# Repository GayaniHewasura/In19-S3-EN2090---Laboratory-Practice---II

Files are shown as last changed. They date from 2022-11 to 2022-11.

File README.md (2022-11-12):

# In19-S3-EN2090---Laboratory-Practice---II
In our third-semester lab project, an analog function generator implemented using the basic elements such as OPAMPs, transistor, and analog components was completed successfully. 
Project Report
FUNCTION GENERATOR
1. G.I. Hewasura 190234E - Square Wave, Triangular Wave, PWM generation
2. T. Jayabawan 190250A - Swatooth wave generation
3. D.R. Jayasinghe 190262L - Power supply
4. L.H.T.V. Jayawardane 190274B - Sine wave generation
Supervisor: Mr. Pasan Dissanayake
November 12, 2022

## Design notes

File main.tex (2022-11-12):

\documentclass[11pt]{article}
\usepackage[utf8]{inputenc}
\usepackage[a4paper, margin=1in]{geometry}
\usepackage{graphicx}
\usepackage{amssymb}
\usepackage{gensymb} % for advanced symbols
\usepackage{amsmath}
\usepackage{amssymb}
\usepackage{multicol}
\setlength{\columnsep}{1cm}
\usepackage{wrapfig}
\usepackage{float}
\usepackage{appendix}
\usepackage{hyperref}
\usepackage{float}

\graphicspath{ {Images/} }
\hypersetup{
    colorlinks=true,
    linkcolor=blue,
    filecolor=magenta,      
    urlcolor=blue,
    pdftitle={Overleaf Example},
    pdfpagemode=FullScreen,
    }
\urlstyle{same}

\begin{document}

\begin{center}
\textbf{Department of Electronic and Telecommunication Engineering\\[10 pt]University of Moratuwa \\[20 pt] EN2090  Laboratory Practice - II \\[20 pt]}



\begin{huge}
\vspace{30mm}
\textbf{Project Report \\[20 pt] FUNCTION GENERATOR} \\[100 pt]
\end{huge}

\begin{tabular}{c c c }
1. & G.I. Hewasura & 190234E  \\
2. & T. Jayabawan  & 190250A  \\ 
3. & D.R. Jayasinghe & 190262L  \\  
4. & L.H.T.V. Jayawardane & 190274B
\end{tabular}

\textbf{\\[20 pt]Supervisor: Mr. Pasan Dissanayake\\[10 pt]}

\begin{large}
\today
\end{large}

\end{center}
\thispagestyle{empty} 
\newpage

\begin{multicols}{2}
[
\rule{\textwidth}{0.5pt}
\begin{abstract}
    Most of the electronics applications require various wave forms. From finding the characteristics of OPAMPs and diodes to testing the inner workings of the audio amplifier these wave forms are used. This report discusses about an analog function generator which can produce sine, square, triangular and saw tooth wave forms at the range of 20Hz to 20000Hz in frequency where the output voltage varies from -5v to 10v.
\end{abstract}
\rule{\textwidth}{0.5pt}
]
\tableofcontents

\section{Introduction}
Analog function generator is an electronic device which is implemented using the basic elements such as OPAMPs and other passive elements. This project "analog function generator" is made as a report covering the aspects of building it physically. First, the methodology used to implement the requirements is discussed. In this part the implementations with circuit diagrams and the principles are discussed. Next the results are described, for each wave forms the output through the oscilloscope are presented and the 

\section{Method}

\subsection{Waveform Generation}

\subsubsection{Square Wave with PWM}
An astable mutivibrator circuit is used in the generation process of the square wave where a Schmitt trigger logic gate is combined with a capacitor. The Schmitt trigger action changes the state between an upper and a lower threshold level as the input voltage signal increase and decrease about the input terminal. When the charge across the capacitor is higher than the Schmitt trigger higher threshold level since the voltage of the positive terminal is higher than the negative terminal, the output result to be logic “0” and vice versa. The period of the square wave changes with the R*C value, a potentiometer is used in the place of R to change the frequency. \\ The PWM signal is generated by sending the triangular waveform generated between the capacitor and the potentiometer through a comparator circuit. The duty cycle of the PWM signal is changed by varying the reference voltage in the positive terminal using the potentiometer in the comparator circuit. The PWM signal generated by the comparator  is sent through a rectifier circuit to achieve a half rectified the PWM signal.
\begin{figure}[H]
    \centering
    
    \caption{Astable Multivibrator Circuit}
    \label{fig:mesh1}
\end{figure}
\begin{figure}[H]
    \centering
    
    \caption{PWM signal genaration}
    \label{fig:mesh1}
\end{figure}
\subsubsection{Triangle Wave}
Triangular wave is extracted in between the capacitor and the potentiometer where the triangular wave is generated as a result of the charging and discharging of the capacitor.
\begin{figure}[H]
    \centering
    
    \caption{Square and triangular pulse generation}
    \label{fig:mesh1}
\end{figure}

\subsubsection{Sine Wave}
Tilan
\subsubsection{Sawtooth Wave}

In order to produce the sawtooth waveform, the magnitude should instantly come to zero from the peak value. To implement this a capacitor can be short circuited but using this the capacitor won’t charge initially. By using a transistor we can find an optimal solution. \\
Here the transistor is in cut-off region to be charged. When capacitor is charged up to required saturation level, a momentary positive pulse is applied at the base of the transistor to send it into saturation. In saturation $V_{CE} = 0$, so capacitor is short circuited and discharges quickly to zero. The positive pulses are given as a PWM signal with a very small duty cycle.

\begin{figure}[H]
    \centering
    
    \caption{Square and triangular pulse generation}
    \label{fig:mesh1}
\end{figure}

\subsection{Output Stage}
According to the given specifications the function generator must be able to drive 50\(\Omega\) load. In general an OPAMP can provide only upto 100mA current which is not enough to drive a 50\(\Omega\) load at 10V pk-pk. In order to accomplish this task we used an OPAMP buffer circuit containing transistor push-pull stage. The maximum current required is about 200mA (10V/50\(\Omega\)). For this we are using 2N2222A NPN and 2N2907A transistors which can support upto 800mA \(I_{C}\) current.

\begin{figure}[H]
    \centering
    
    \caption{Buffer Circuit (using OPAMPS and push-pull stage}
    \label{fig:mesh1}
\end{figure}

\section{Results}
After testing the following results could be obtained relating to different modules in the function generator circuits.

\subsection{Component Selection}

Following are the main components used in the implementation of the analogue function generator.
\vspace{-2mm}

\begin{itemize}
    \setlength\itemsep{-2mm}
    \item TL084CN Quad-OPAMP
    \item AD826AN Dual-OPAMP
    \item 2N2222A, 2N2907A, 2N3904 transistors
    \item resistors, potentiometers, capacitors, etc.
\end{itemize}

\subsubsection*{TL084CN}
TL084CN is a 14-pin Quad Operational Amplifier by Texas Instruments. It has a slew rate of \(20 \; V/\mu s\) and a unity gain bandwidth of 5.25MHz. All the signal generation tasks were carried out using 2 of these OPAMPs. This OPAMPs able to produce both low (40Hz) and high (20kHz) frequency signals with sufficient accuracy.  

\subsubsection*{AD826AN}
AD826AN is an 8-pin Dual Operational Amplifier by Analog Devices. Is has a very high slew rate of \(350 V\mu s\) and a unity gain bandwidth of 40-50MHz. This OPAMP was used in the output stage as a non-inverting amplifier and a buffer before the transistor push-pull stage.

\subsection{Square and PWM wave}
We used two capacitors (\(10nF\) and \(0.33\mu F\)) to achieve lower and higher frequencies respectively in the relaxation oscillator. The PWM control is done using the OPAMP comparator. The following images show rectified square waveforms with different PWM values.

\begin{figure}[H]
    \centering
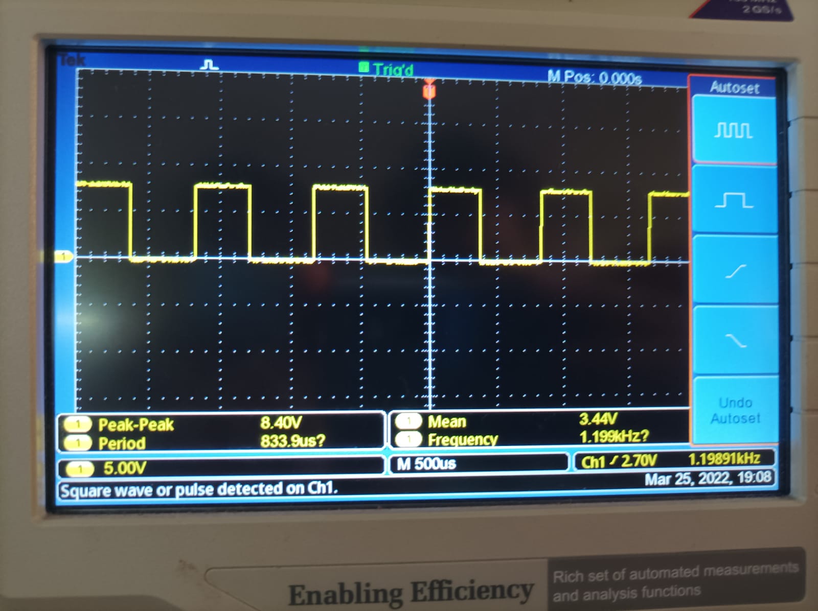
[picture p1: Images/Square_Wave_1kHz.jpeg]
    
    \caption{1kHz Square Wave Signal}
    \label{fig:mesh2}
\end{figure}

\begin{figure}[H]
    \centering
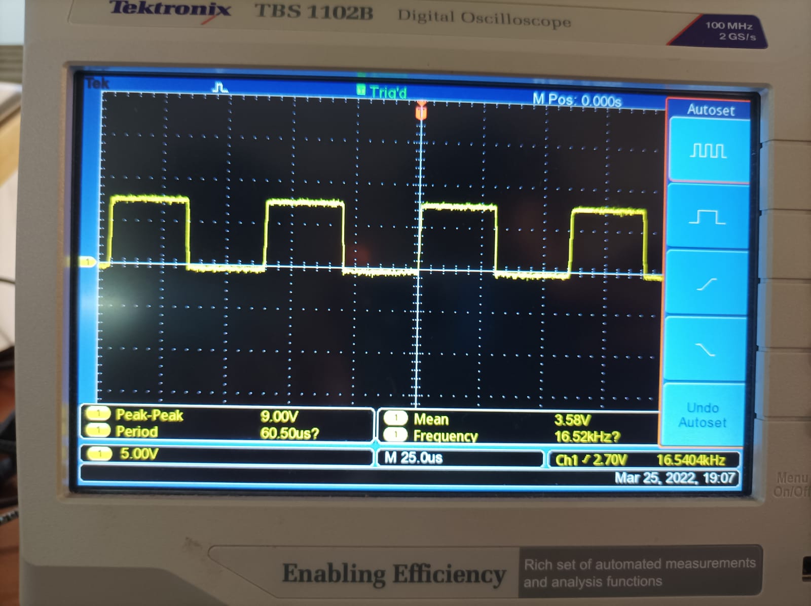
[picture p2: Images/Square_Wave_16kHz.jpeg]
    
    \caption{16kHz Square Wave Signal}
    \label{fig:mesh2}
\end{figure}

\begin{figure}[H]
    \centering
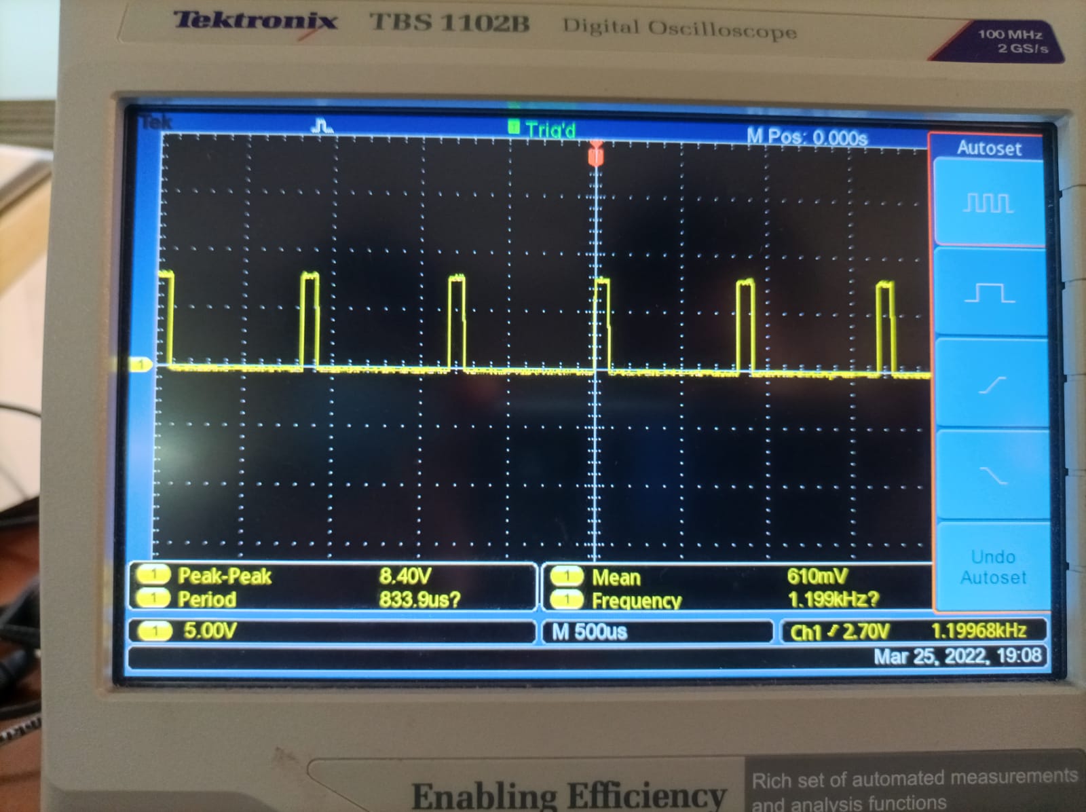
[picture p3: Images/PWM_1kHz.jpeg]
    
    \caption{PWM control of square wave}
    \label{fig:mesh3}
\end{figure}

\begin{figure}[H]
    \centering
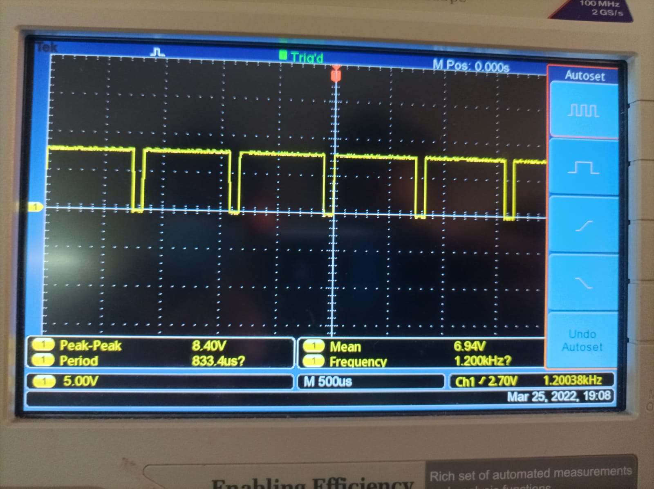
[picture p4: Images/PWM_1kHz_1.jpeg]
    
    \caption{PWM control of square wave}
    \label{fig:mesh4}
\end{figure}

\subsection*{Triangle Wave}

The triangle waveform is obtained as the voltage across the capacitor from the relaxation oscillator. 

\begin{figure}[H]
    \centering
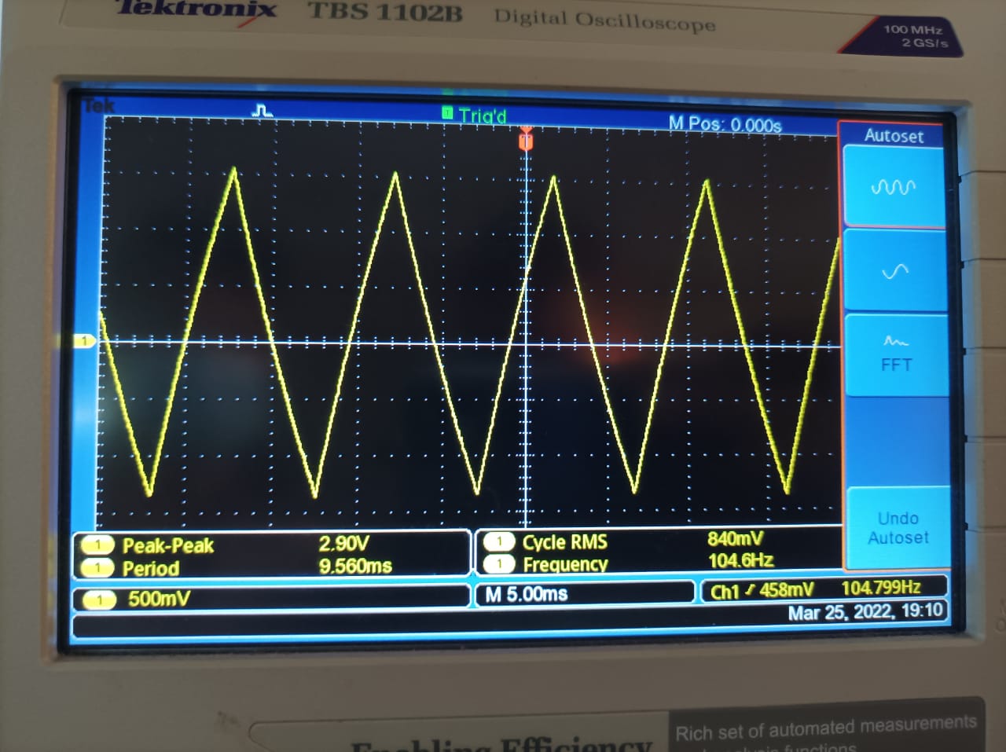
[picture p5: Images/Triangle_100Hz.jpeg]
    
    \caption{100Hz triangle waveform}
    \label{fig:mesh5}
\end{figure}

\begin{figure}[H]
    \centering
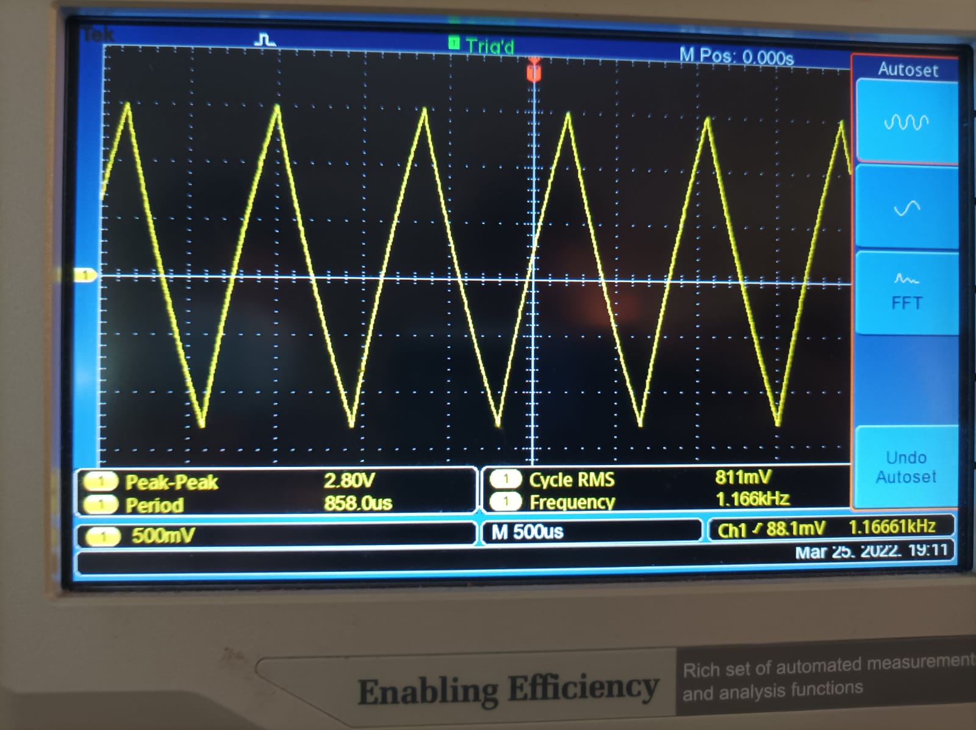
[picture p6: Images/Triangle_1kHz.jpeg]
    
    \caption{1kHz triangle waveform}
    \label{fig:mesh6}
\end{figure}

\begin{figure}[H]
    \centering
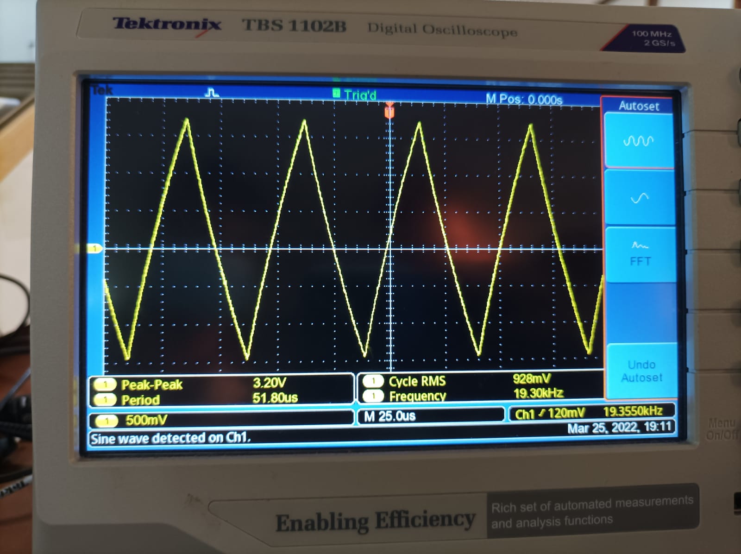
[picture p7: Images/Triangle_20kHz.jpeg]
    
    \caption{20kHz triangle waveform}
    \label{fig:mesh7}
\end{figure}

\subsection*{Sine Wave}

The sine wave is obtained after the triangle waveform is filtered from the low pass filters. From the four filters we used the accurate wave forms could be obtained.

\begin{figure}[H]
    \centering
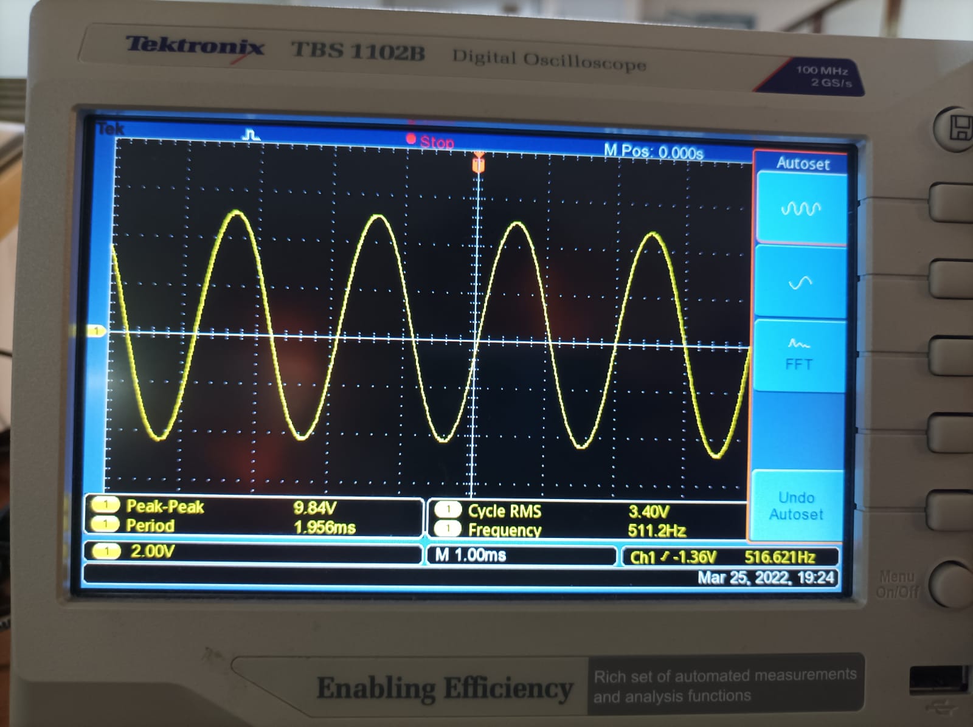
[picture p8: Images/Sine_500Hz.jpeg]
    
    \caption{500Hz sine waveform}
    \label{fig:mesh5}
\end{figure}

\begin{figure}[H]
    \centering
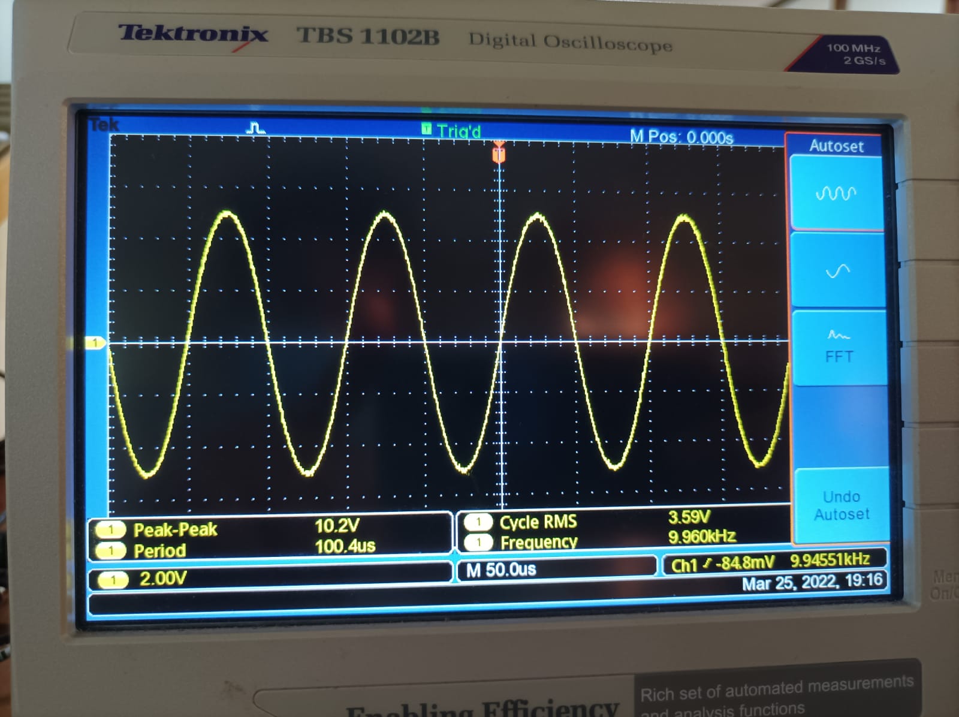
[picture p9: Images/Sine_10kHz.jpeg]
    
    \caption{10kHz sine waveform}
    \label{fig:mesh6}
\end{figure}

\begin{figure}[H]
    \centering
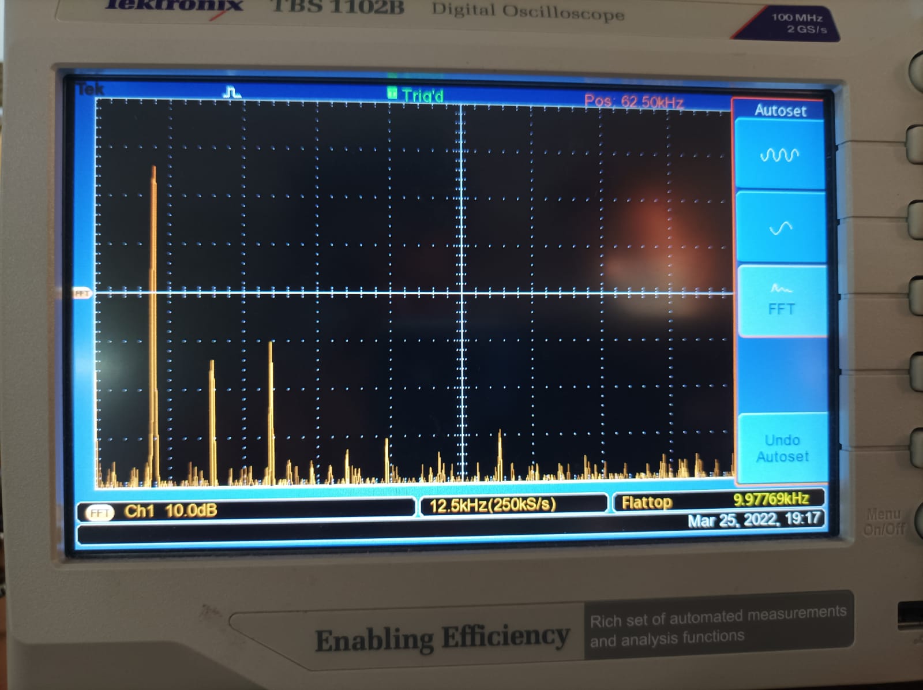
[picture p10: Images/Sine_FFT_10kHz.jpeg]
    
    \caption{Frequency spectrum of 10kHz sine waveform}
    \label{fig:mesh7}
\end{figure}

\section{Discussion}

Following are some of the issues we encountered when designing the analogue function generator. We were able to fix some these issues.

\subsubsection*{Shape of the Triangle Waveform}
The triangle wave which was obtained as the capacitor voltage of the relaxation oscillator, was not exactly triangular in shape. At closer inspection it is possible to see a curve similar to that of a capacitor charging and discharging. This could have been avoided by integrating the square wave, using an \textbf{OPAMP integrator} circuit instead. But we decided not to implement it because, the waveform was very nearly triangular. 
\\
\textbf{\textcolor{red}{image of a distorted triangle wave}}

\subsubsection*{Amplitude reduction of Sine and Sawtooth functions when increasing frequency}

This is another issue that could not be completely resolved in our design. As the frequency is increased, the amplitude of both sine and sawtooth wave reduced dramatically. This happened in each waveform due to the following reason;
\begin{itemize}
    \item \textbf{Sine wave} - Once the frequency was increased past the cutoff frequency of the filter, the gain reduction caused the amplitude of the waveform to drop. 
    \item \textbf{Sawtooth Wave} - \textbf{\textcolor{red}{Reason for the decrease in amplitude}}
\end{itemize}

The method currently used to overcome this issue is to, increase the amplitude at the output stage to counter balance the amplitude reduction resulted by frequency change.

\end{multicols}

\newpage

\section{Appendices}

\subsection{Appendix I - PCB Layout}

\begin{multicols}{2}
\begin{figure}[H]
    \centering
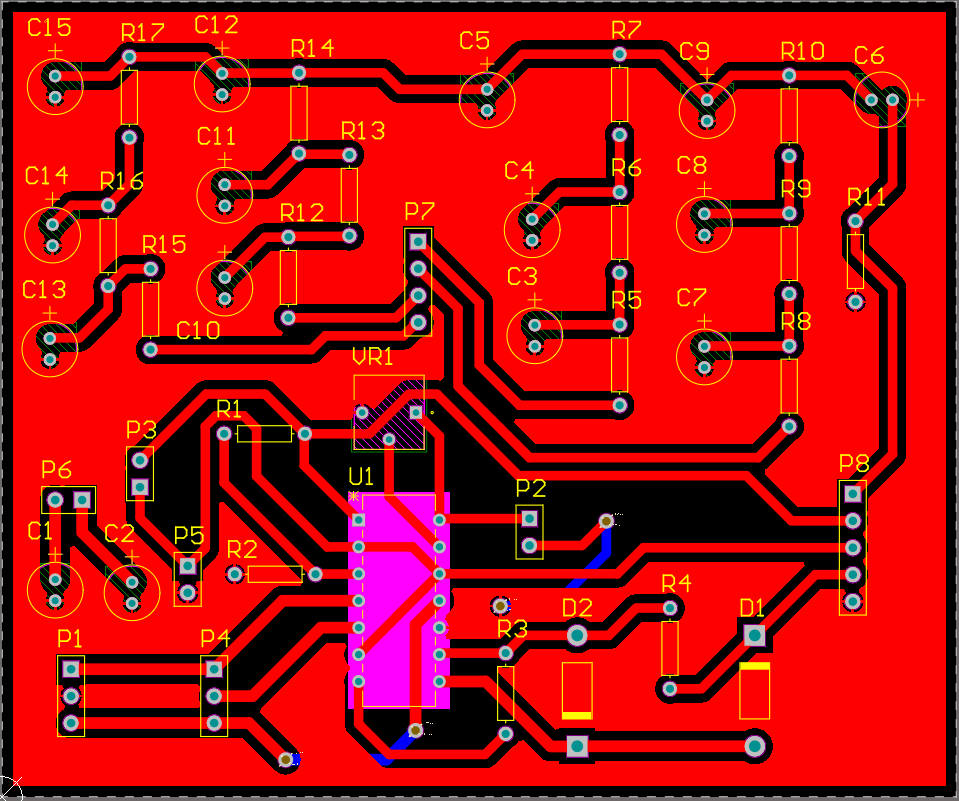
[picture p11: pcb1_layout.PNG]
    
    \caption{PCB 1 - Triangle, Square, Sine Wave generation}
    \label{fig:mesh6}
\end{figure}

\begin{figure}[H]
    \centering
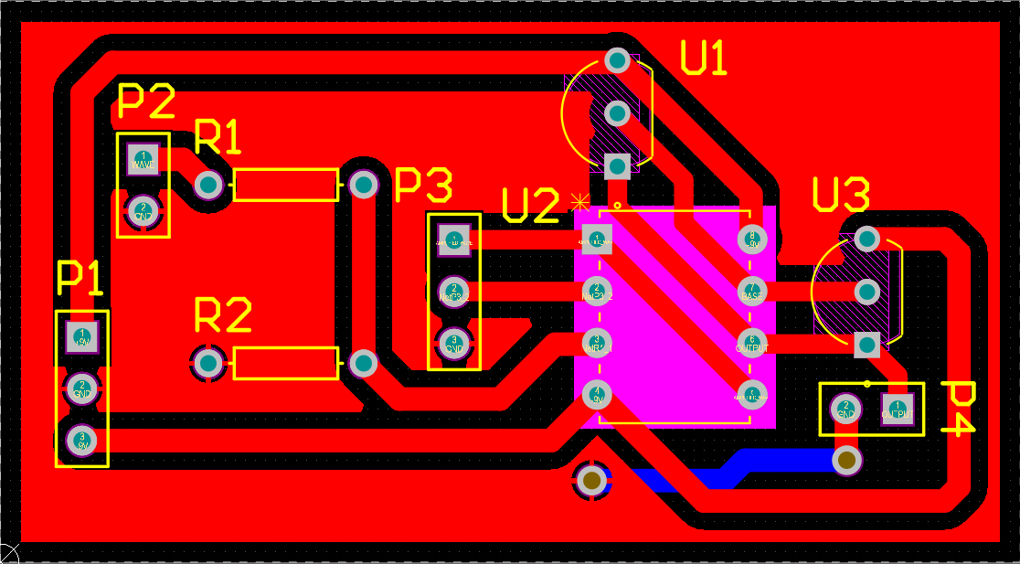
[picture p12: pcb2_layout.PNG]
    
    \caption{PCB 2 - Output Stage }
    \label{fig:mesh6}
\end{figure}

\begin{figure}[H]
    \centering
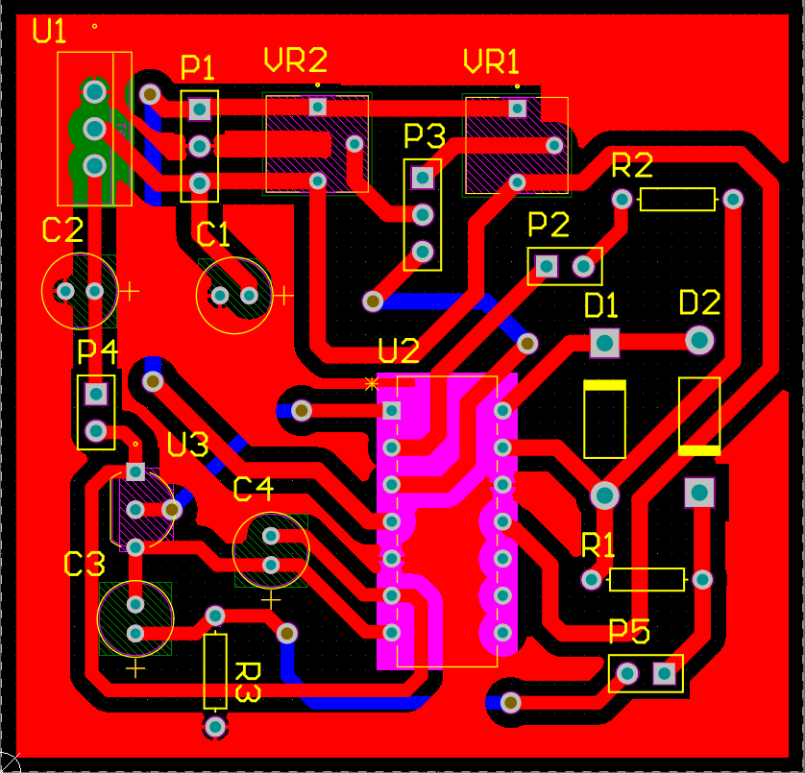
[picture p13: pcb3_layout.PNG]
    
    \caption{PCB 3 - Sawtooth Wave Generation}
    \label{fig:mesh6}
\end{figure}

\end{multicols}

\section{Appendix II - Enclosure}

\newpage

\section{Appendix III - Datasheet}

\rule{\textwidth}{0.5pt}

\begin{center}
    \begin{large}
    \textbf{Analogue Function Generator - Datasheet}
    \end{large}

\end{center}

\subsection*{Features}
\begin{itemize}
    \setlength\itemsep{-2mm}
    \item 5 output functions
    \item Adjustable frequency from 40Hz to 20kHz
    \item Amplitude can be adjusted within \(\pm\)7V
    \item Can drive small loads
\end{itemize}

\subsection*{Description}

Analogue Function Generator is designed completely using analogue electronic components and it is capable of producing the following output functions.
\begin{itemize}
    \setlength\itemsep{-2mm}
    \item Triangle Wave
    \item Square Wave (50\% duty)
    \item Square Wave PWM (variable duty cycle)
    \item Sine Wave
    \item Sawtooth Wave
\end{itemize}

The device can output these waveforms with minimum distortion approximately within a range of 40Hz - 20kHz. It is possible to adjust the amplitude of each of the waveforms within a range about of \(\pm\)7V. The fuction generator can be used for multiple electronics and communications applications such as testing equipments, analyse Audio Systems, etc.

\subsection*{Specifications}

\subsubsection*{Power Supply}

\begin{multicols}{2}
\begin{tabular}{ | c |  c |  c | }
\hline
\multicolumn{3}{| c  |}{Input} \\
\hline
Min. Input Voltage & 7 & V AC rms\\
\hline
Max. Input Voltage & 24 & V AC rms \\
\hline
Typ. Input Voltage & 9 - 15 & V AC rms \\
\hline

\end{tabular}

\begin{tabular}{ | c |  c |  c | }
\hline
\multicolumn{3}{| c  |}{Output} \\
\hline
Output Voltage & \(\pm\)9 & V DC\\
\hline
Max. Output Current & 1.5 & A \\
\hline
\end{tabular}
\end{multicols}

\subsubsection*{Function Generator Output}

\subsubsection*{Output Frequency Ranges}

\begin{tabular}{| c | c | c |}
\hline
Function &  Min. Frequency & Max. Frequency \\
\hline
Triangle & 41 Hz & ~30 kHz\\
\hline
Square (50\% Duty) & 44 Hz & ~20 kHz\\
\hline
Square Wave (PWM) & 44 Hz & ~22 kHz \\ 
\hline
Sine Wave & 80 Hz & ~20 kHz\\
\hline
Sawtooth Wave & 110 Hz & ~10 kHz \\ 
\hline
\end{tabular}

\vspace{5mm}
\begin{multicols}{2}
\subsubsection*{PWM Duty Cycle Range}

\begin{tabular}{| c | c | c |}
\hline
Frequency Range & Duty Cycle \\
\hline
40 - 1 kHz & 1.6\% - 98.5\% \\
\hline
1 - 10 kHz & 2\% - 97\% \\
\hline
10 - 20 kHz & 4\% - 95\% \\
\hline
\end{tabular}

\subsubsection*{Sine Filter Selection}

\begin{tabular}{| c | c | c |}
\hline
 & Frequency Range\\
\hline
Filter 1 & 44 Hz - 400 Hz \\
\hline
Filter 2 & 400 Hz - 2 kHz \\
\hline
Filter 3 & 2 kHz - 10 kHz \\
\hline
Filter 4 & 10 kHz - 20 kHz \\
\hline
\end{tabular}
\end{multicols}

\end{document}

\end{document}

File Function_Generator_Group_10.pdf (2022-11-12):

Department of Electronic and Telecommunication Engineering

University of Moratuwa

EN2090 Laboratory Practice - II


# Project Report

# FUNCTION GENERATOR

1. | G.I. Hewasura | 190234E
2. | T. Jayabawan | 190250A
3. | D.R. Jayasinghe | 190262L
4. | L.H.T.V. Jayawardane | 190274B

Supervisor: Mr. Pasan Dissanayake

November 12, 2022

Abstract
Most of the electronics applications require various wave forms. From finding the characteristics of OPAMPs and diodes to testing the inner workings of the audio amplifier these wave forms are used. This report discusses about an analog function generator which can produce sine, square, triangular and saw tooth wave forms at the range of 20Hz to 20000Hz in frequency where the output voltage varies from -5v to 10v.

## Contents

1 Introduction | 2
2 Methodology | 2
2.1 Waveform Generation . . . . | 2
2.1.1 | Square Wave and PWM | 2
2.1.2 | Triangle Wave . . . . | 3
2.1.4 | Sawtooth Wave . . . . | 3
2.4 Circuit Block Diagram . . . . | 5
3 Results | 5
3.1 Square and PWM wave . . . | 5
4 Discussion | 7
5 Member Contribution | 8
6 References | 8
7 Appendices | 9
7.1 Appendix I - PCB Layout . . | 9
8 Appendix II - Enclosure | 9
9 Appendix III - Datasheet | 10

## 1 Introduction

Analog function generator is an electronic device implemented using the basic elements such as OPAMPs, transistor and analogue components.Function generators are used for many application such as testing and design of electronic devices, etc. This reports presents the design and physical implementation of an analogue function generator. First, the methodology used to implement the requirements is presented. In this part the implementations with circuit diagrams and the principles are discussed. Next the results are described. For each wave forms the output through the oscilloscope are presented and in the final section the results and the possible further improvements are discussed.

## 2 Methodology

### 2.1 Waveform Generation

### 2.1.1 Square Wave and PWM

An astable mutivibrator circuit is used in the generation process of the square wave where a Schmitt trigger is combined with a capacitor. The Schmitt trigger action changes the state between an upper and a lower threshold level as the input voltage signal increase and decrease about the input terminal. When the charge across the capacitor is higher than the Schmitt trigger higher threshold level since the voltage of the positive terminal is higher than the negative terminal, the output result to be logic “0” and vice versa. The period of the square wave changes with the RC value, a potentiometer is used as R to change the frequency.
The PWM signal is generated by sending the triangular waveform, generated at the capacitor, through a comparator circuit. The duty cycle of the PWM signal is changed by varying the reference voltage of the comparator. A precision rectifier circuit is used to rectify the square and PWM waveforms. Following equation is used to determine the period(T) of the square/triangle wave output of the astable multivibrator circuit.

β =

R1
R1 + R2

T = 2RC ln(

1 + β
1 − β

)

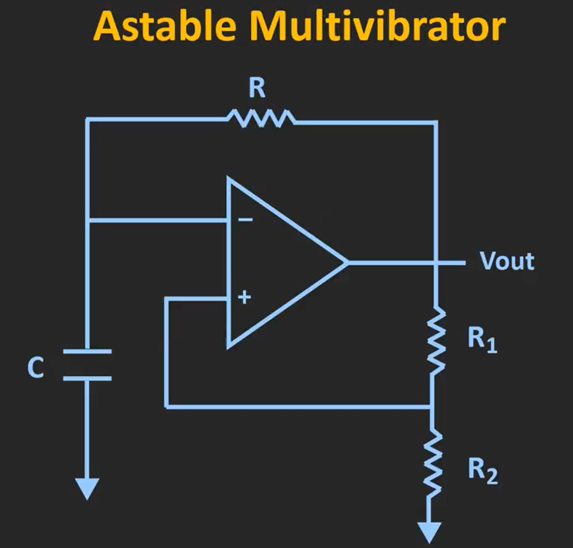
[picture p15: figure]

Figure 1: Astable Multivibrator Circuit

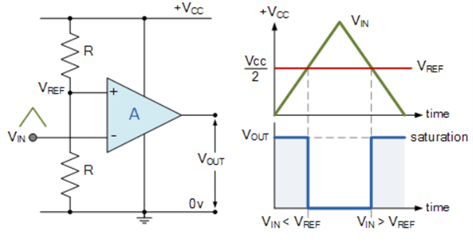
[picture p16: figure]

Figure 2: PWM signal genaration

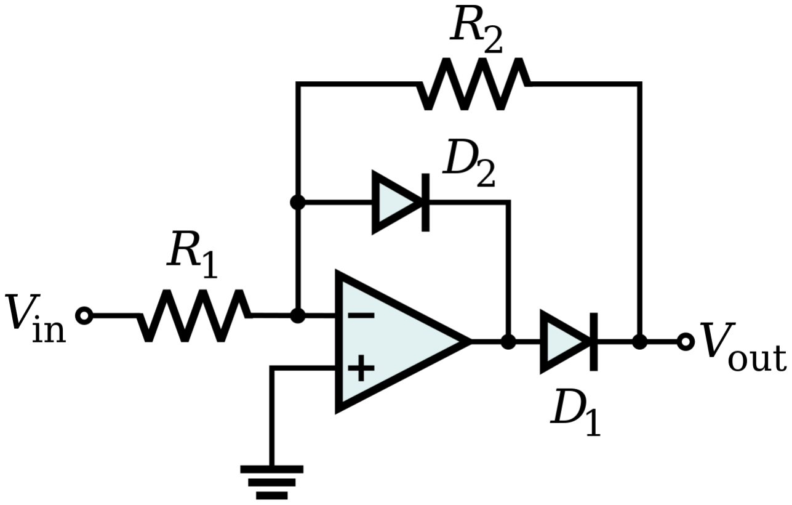
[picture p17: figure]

Figure 3: Precision rectifier circuit

### 2.1.2 Triangle Wave

Triangular wave is extracted in between the capacitor and the potentiometer where the triangular wave is generated as a result of the charging and discharging of the capacitor.

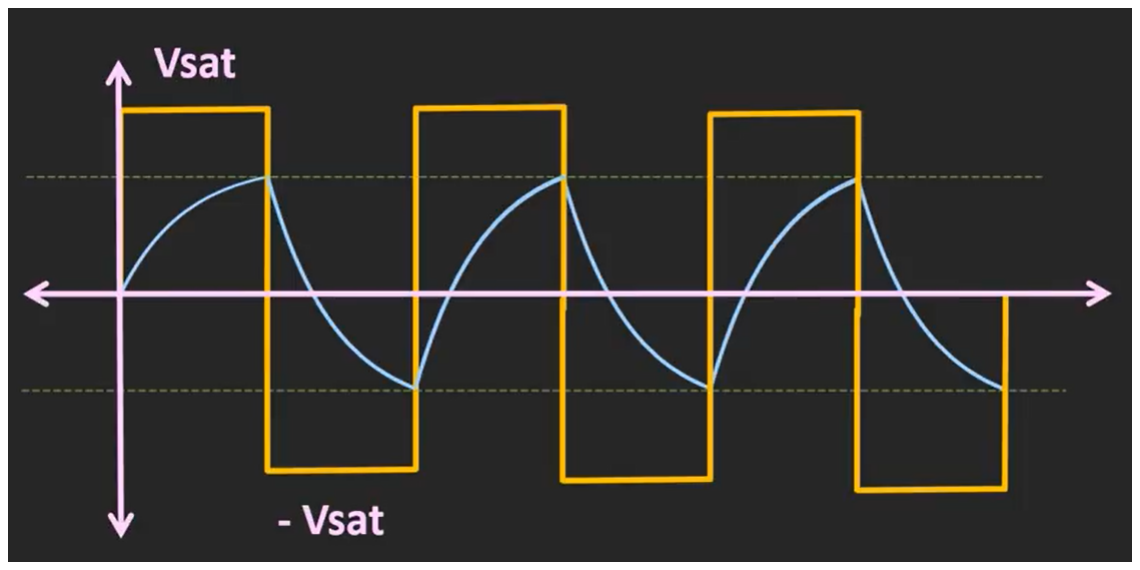
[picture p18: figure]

Figure 4: Square and triangular pulse generation

### 2.1.3 Sine Wave

The Sine Wave generation was done by lowpass filtering the traingle wave obtained from the relaxation oscillator. 3rd order RC passive filters were used for this purpose. As the filter output was frequncy dependent we implemented 4 filters with different resistor and capacitor values. The cut off frequency of each of the filters was obtained theoretically using the following equation,

fc =

1

2π(R1C1R2C2R3C3)

1
3

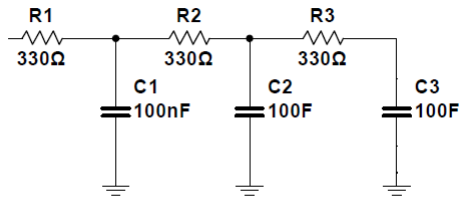
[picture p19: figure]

Figure 5: 3rd order RC lowpass filter

| Frequency Range
Filter 1 | 80 Hz - 400 kHz
Filter 2 | 400 Hz - 2 kHz
Filter 3 | 2 kHz - 8 kHz
Filter 4 | 8 kHz - 20 kHz

Table 1: Filters with their frequncy ranges

### 2.1.4 Sawtooth Wave

In order to produce the sawtooth waveform, the magnitude should instantly come to zero from the peak value. To implement this a capacitor can be short circuited but using this the capacitor won’t charge initially. By using a transistor we can find an optimal solution. Here the transistor is in cut-off region to be charged. When capacitor is charged up to required saturation level, a momentary positive pulse is applied at the base of the transistor to send it into saturation. In saturation VCE = 0, so capacitor is short circuited and discharges quickly to zero. The positive pulses are given as a PWM signal with a very small duty cycle.

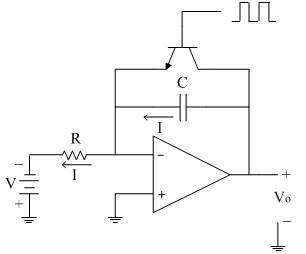
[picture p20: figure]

Figure 6: Square and triangular pulse generation

### 2.2 Output Stage

According to the given specifications the function generator must be able to drive 50Ω load. In general an OPAMP can provide only upto 100mA current which is not enough to drive a 50Ω load at 10V pk-pk. In order to accomplish this task we used an OPAMP buffer circuit containing transistor push-pull stage. The maximum current required is about 200mA (10V/50Ω). For this we are using 2N2222A NPN and 2N2907A transistors which can support upto 800mA IC current.

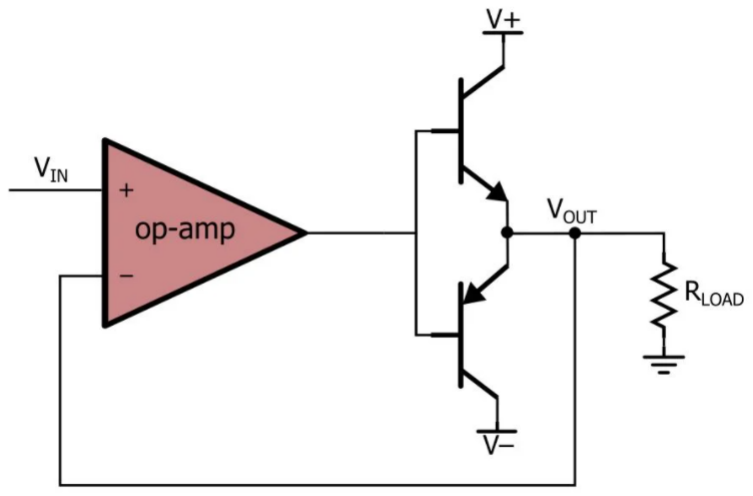
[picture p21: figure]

Figure 7: Buffer Circuit (using OPAMPS and push-pull stage

### 2.3 Power Supply

The power supply will take input AC voltages in the range of 7 - 24 V (rms) and output a dual voltage of ±9V. This dual voltages are used to operate all the components including the OPAMPs. A rectifier bridge (KBP307) and positive and negative voltage regulators were used for this purpose (LM7809 LM7909).

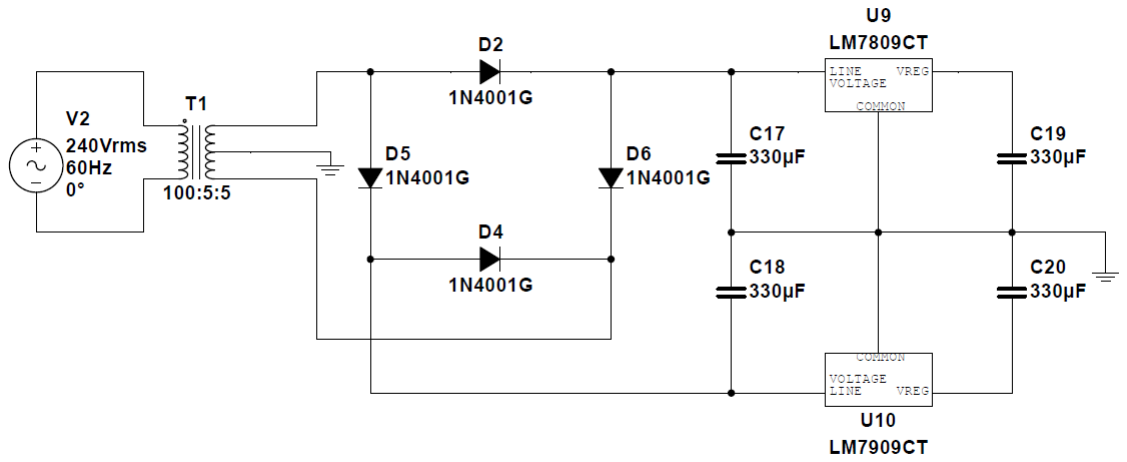
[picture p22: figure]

Figure 8: ±9V power supply

### 2.4 Circuit Block Diagram

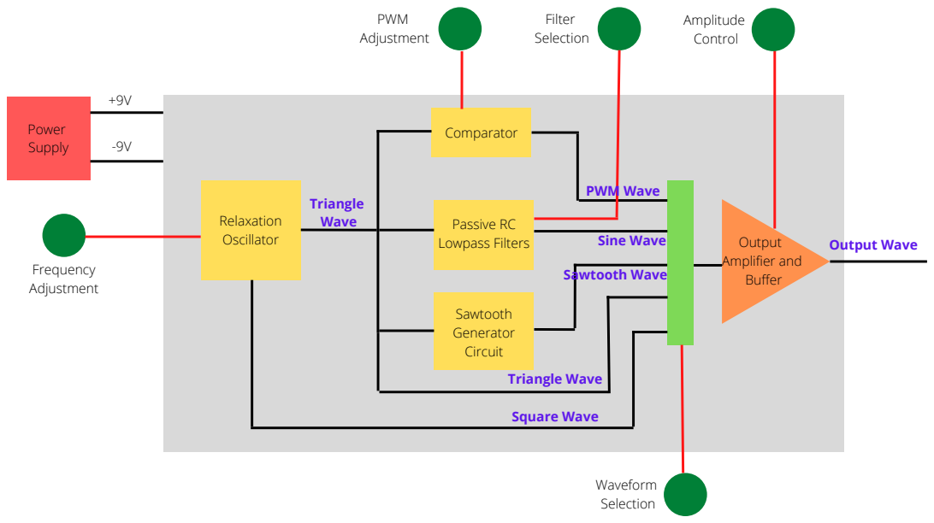
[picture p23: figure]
Power Supply; Relaxation Oscillator; Passive RC Lowpass Filters; Sawtooth Generator Circuit; Comparator; Output Amplifier and Buffer; Frequency Adjustment; PWM Adjustment; Filter Selection; Waveform Selection; Amplitude Control; Triangle Wave; Square Wave; PWM Wave; Sine Wave; Sawtooth Wave; Output Wave

Figure 9: Circuit Block Diagram

### 2.5 Component Selection

Following are the main components used in the implementation of the analogue function generator.
- TL084CN Quad-OPAMP
- AD826AN Dual-OPAMP
- 2N2222A, 2N2907A, 2N3904 transistors
- resistors, potentiometers, capacitors, etc.

TL084CN

TL084CN is a 14-pin Quad Operational Amplifier by Texas Instruments. It has a slew rate of 20 V /µs and a unity gain bandwidth of 5.25MHz. All the signal generation tasks were carried out using 2 of these OPAMPs. This OPAMPs able to produce both low (40Hz) and high (20kHz) frequency signals with sufficient accuracy.

AD826AN

AD826AN is an 8-pin Dual Operational Amplifier by Analog Devices. Is has a very high slew rate of 350V µs and a unity gain bandwidth of 40-50MHz. This OPAMP was used in the output stage as a non-inverting amplifier and a buffer before the transistor push-pull stage.

## 3 Results

After testing the following results could be obtained relating to different modules in the function generator circuits.

### 3.1 Square and PWM wave

We used two capacitors (10nF and 0.33µF) to achieve lower and higher frequencies respectively in the relaxation oscillator. The PWM control is done using the OPAMP comparator. The following images show rectified square waveforms with different PWM values.


Figure 10: 1kHz Square Wave Signal


Figure 11: 16kHz Square Wave Signal


Figure 12: PWM control of square wave


Figure 13: PWM control of square wave

Triangle Wave

The triangle waveform is obtained as the voltage across the capacitor from the relaxation oscillator.


Figure 14: 100Hz triangle waveform


Figure 15: 1kHz triangle waveform


Figure 16: 20kHz triangle waveform

Sine Wave

The sine wave is obtained after the triangle waveform is filtered from the low pass filters. From the four filters we used the accurate wave forms could be obtained.


Figure 17: 500Hz sine waveform


Figure 18: 10kHz sine waveform


Figure 19: Frequency spectrum of 10kHz sine waveform

## 4 Discussion

Following are some of the issues we encountered when designing the analogue function generator. We were able to fix some these issues.

Shape of the Triangle Waveform

The triangle wave which was obtained as the capacitor voltage of the relaxation oscillator, was not exactly triangular in shape. At closer inspection it is possible to see a curve similar to that of a capacitor charging and discharging. This could have been avoided by integrating the square wave, using an OPAMP integrator circuit instead. But we decided not to implement it because, the waveform was very nearly triangular.

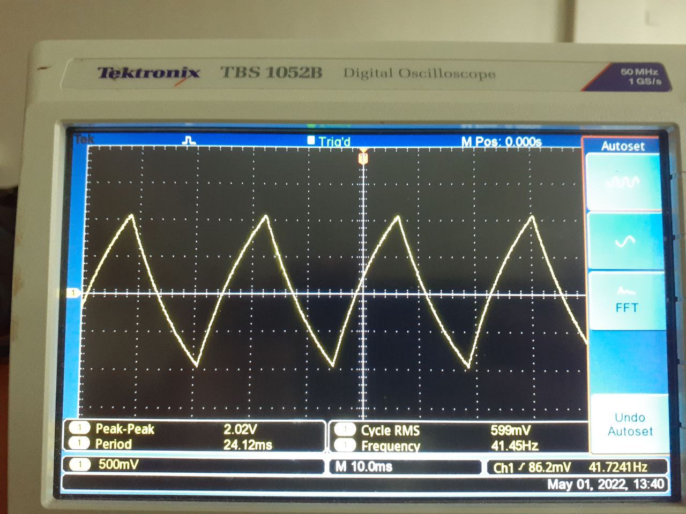
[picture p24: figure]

Figure 20: 1Distored triangle wave

Amplitude reduction of Sine and Sawtooth functions when increasing frequency

This is another issue that could not be completely resolved in our design. As the frequency is increased, the amplitude of both sine and sawtooth wave reduced dramatically. This happened in each waveform due to the following reason;

- Sine wave - Once the frequency was increased past the cutoff frequency of the filter, the gain reduction caused the amplitude of the waveform to drop.
- Sawtooth Wave - RC circuit in the OPAMP integrator in the sawtooth generator circuit gave a frequency dependent output. Therefore, as the frequency was increased it caused the amplitude to drop.

The method currently used to overcome this issue is to, increase the amplitude at the output stage to counter balance the amplitude reduction resulted by frequency change.

## 5 Member Contribution

Member | Contribution
190234E Hewasura G.I. | Squre and Triangle Wave Genration, Enclosure De-sign
190250A Jayabawan T. | Sawtooth Generator Cir-cuit, PCB Design
190262L Jayasinghe D.R. | Power Supply, Output am-plifer, PCB Design
190274B Jayawardhane L.H.T.V. | Sine Wave Generation, Sol-dering

## 6 References

1. https://www.electronics-notes.com/articles/test-methods/signal-generators/function-generator.php (https://www.electronics-notes.com/articles/test-methods/signal-generators/function-generator.php)
2. https://www.electronics-tutorials.ws/
filter/second-order-filters.html (https://www.electronics-tutorials.ws/filter/second-order-filters.html)
3. https://www.elprocus.com/what-is-a-square-wave-generator-circuit-diagram/
4. https://www.electronics-tutorial.net/analog-integrated-circuits/multivibrators/
sawtooth-waveform-generator (https://www.electronics-tutorial.net/analog-integrated-circuits/multivibrators/sawtooth-waveform-generator)
5. https://www.allaboutcircuits.com/technical-articles/how-to-buffer-an-op-amp-output-for-higher-current-part-2/ (https://www.allaboutcircuits.com/technical-articles/how-to-buffer-an-op-amp-output-for-higher-current-part-2/)
6. https://en.wikipedia.org/wiki/Precision
rectifier (https://en.wikipedia.org/wiki/Precision_rectifier)

## 7 Appendices


### 7.1 Appendix I - PCB Layout

Figure 21: PCB 1 - Triangle, Square, Sine Wave generation

Figure 22: PCB 2 - Output Stage

Figure 23: PCB 3 - Sawtooth Wave Generation

## 8 Appendix II - Enclosure

Figure 24: Enclosure - View 1

Figure 25: Enclosure - View 2

## 9 Appendix III - Datasheet

Analogue Function Generator - Datasheet

Features

- 5 output functions
- Adjustable frequency from 40Hz to 20kHz
- Amplitude can be adjusted within ±7V
- Can drive small loads

Description

Analogue Function Generator is designed completely using analogue electronic components and it is capable of producing the following output functions.

- Triangle Wave
- Square Wave (50% duty)
- Square Wave PWM (variable duty cycle)
- Sine Wave
- Sawtooth Wave

The device can output these waveforms with minimum distortion approximately within a range of 40Hz - 20kHz. It is possible to adjust the amplitude of each of the waveforms within a range about of ±7V. The fuction generator can be used for multiple electronics and communications applications such as testing equipments, analyse Audio Systems, etc.

Specifications

Power Supply

Input
Min. Input Voltage | 7 | V AC rms
Max. Input Voltage | 24 | V AC rms
Typ. Input Voltage | 9 - 15 | V AC rms

Output
Output Voltage | ±9 | V DC
Max. Output Current | 1.5 | A

Function Generator Output

Output Frequency Ranges

Function | Min. Frequency | Max. Frequency
Triangle | 41 Hz | 30 kHz
Square (50% Duty) | 44 Hz | 20 kHz
Square Wave (PWM) | 44 Hz | 22 kHz
Sine Wave | 80 Hz | 20 kHz
Sawtooth Wave | 110 Hz | 10 kHz

PWM Duty Cycle Range

Frequency Range | Duty Cycle
40 - 1 kHz | 1.6% - 98.5%
1 - 10 kHz | 2% - 97%
10 - 20 kHz | 4% - 95%

Sine Filter Selection

| Frequency Range
Filter 1 | 44 Hz - 400 Hz
Filter 2 | 400 Hz - 2 kHz
Filter 3 | 2 kHz - 10 kHz
Filter 4 | 10 kHz - 20 kHz

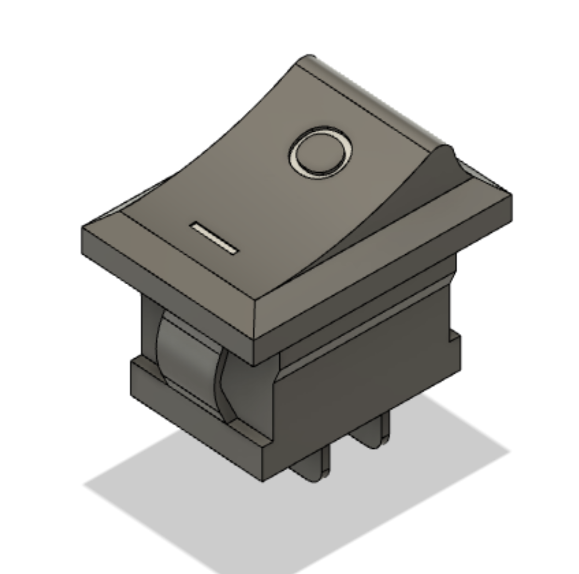
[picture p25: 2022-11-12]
function generator enclosure/mini/Rocker Switch.PNG

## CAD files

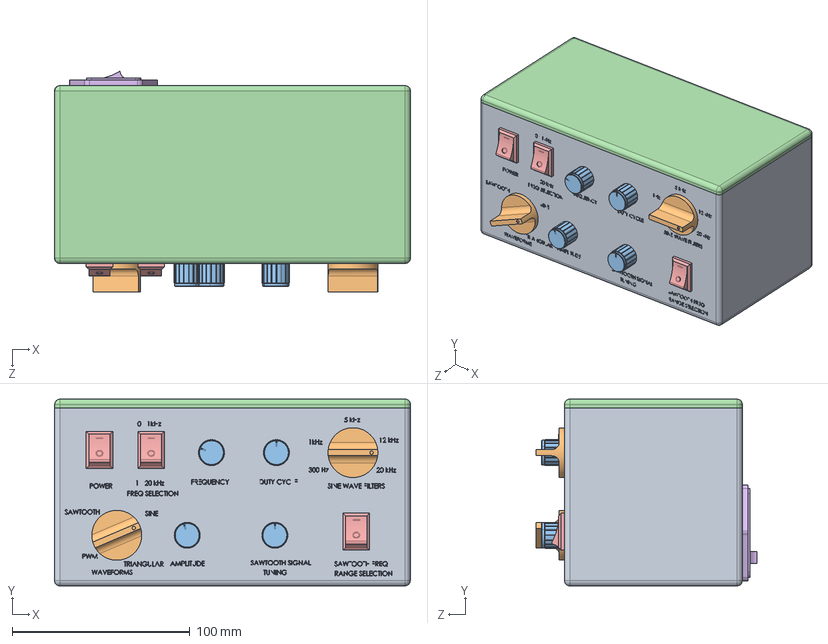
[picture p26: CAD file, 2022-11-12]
function generator enclosure/Assem1.SLDASM
200.1 x 105.0 x 124.2 mm
Perilla aire acondicionado x 2
Potentiometer knob_A15x17-PK-AB-K-I.stp x 4
lid
Square Rocker Switch v2.step x 3
AC Input Connector and Switch.step

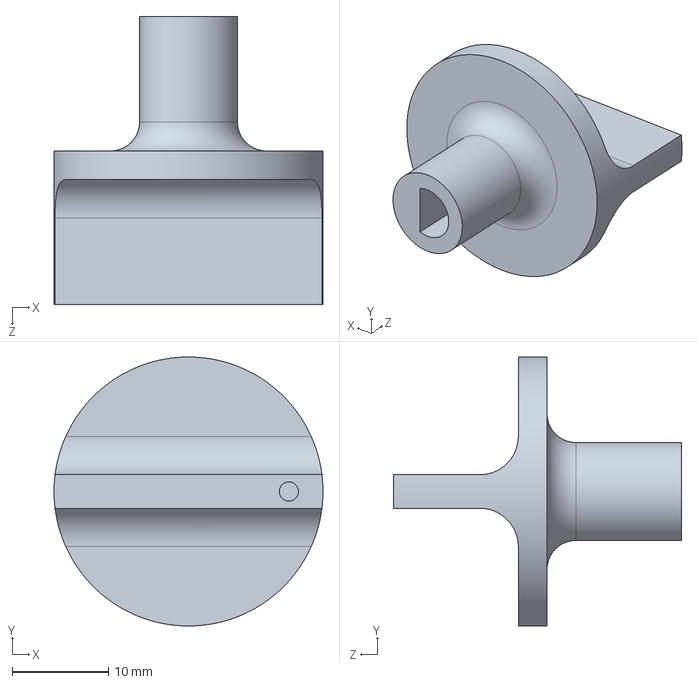
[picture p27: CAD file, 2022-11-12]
function generator enclosure/2_way_switch/Perilla aire acondicionado.SLDPRT
28.0 x 28.0 x 30.0 mm

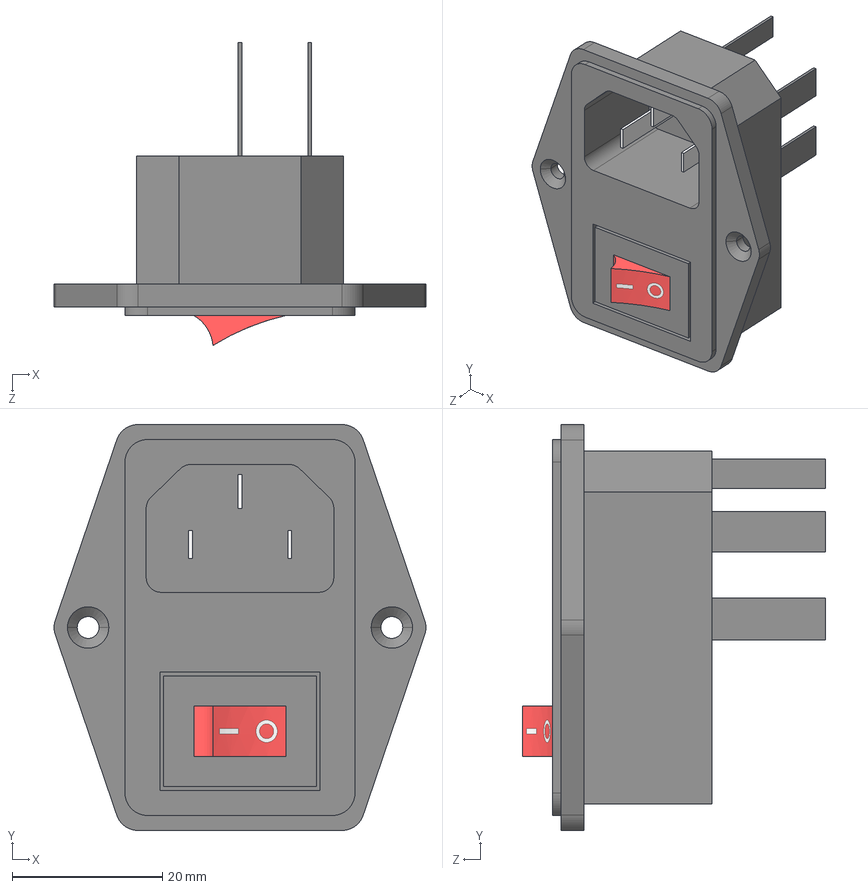
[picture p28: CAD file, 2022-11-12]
function generator enclosure/ac/AC Input Connector and Switch.STEP
49.5 x 54.0 x 40.3 mm

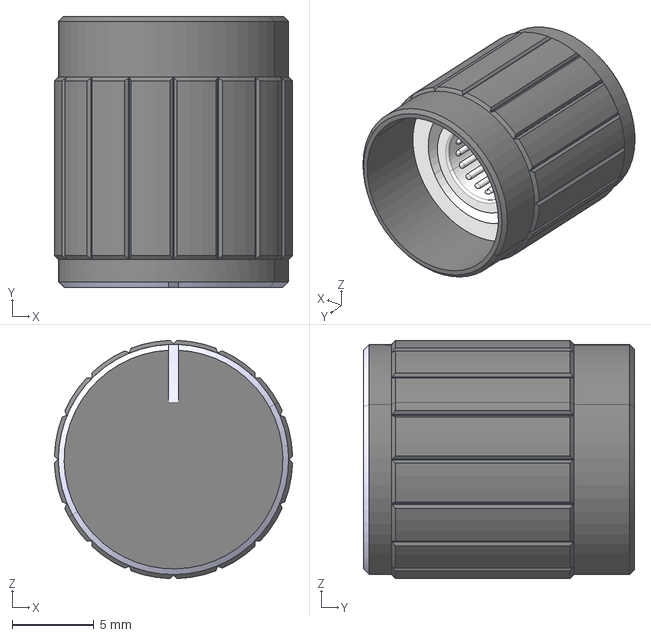
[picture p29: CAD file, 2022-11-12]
function generator enclosure/c_k_continous/Potentiometer knob_A15x17-PK-AB-K-I.stp
14.6 x 16.6 x 14.6 mm

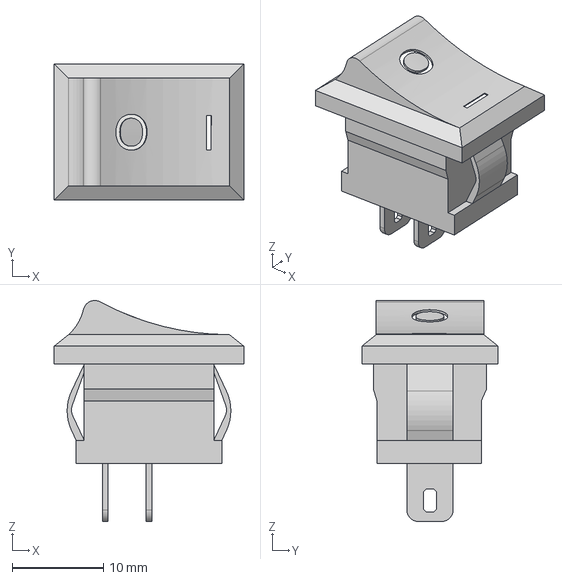
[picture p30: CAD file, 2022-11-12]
function generator enclosure/mini/Square Rocker Switch v2.step
20.8 x 15.0 x 24.3 mm

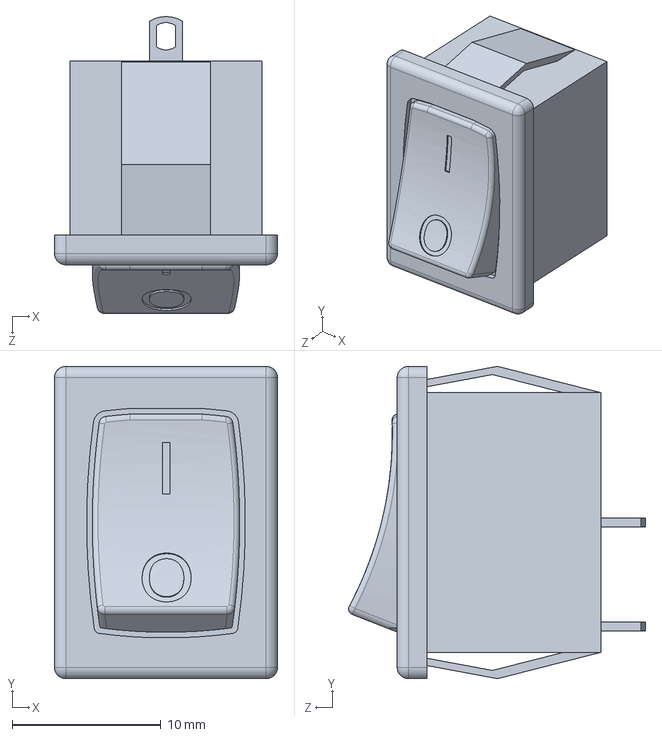
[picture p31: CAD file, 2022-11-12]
function generator enclosure/rocker switch 1.SLDPRT
15.0 x 21.0 x 20.0 mm

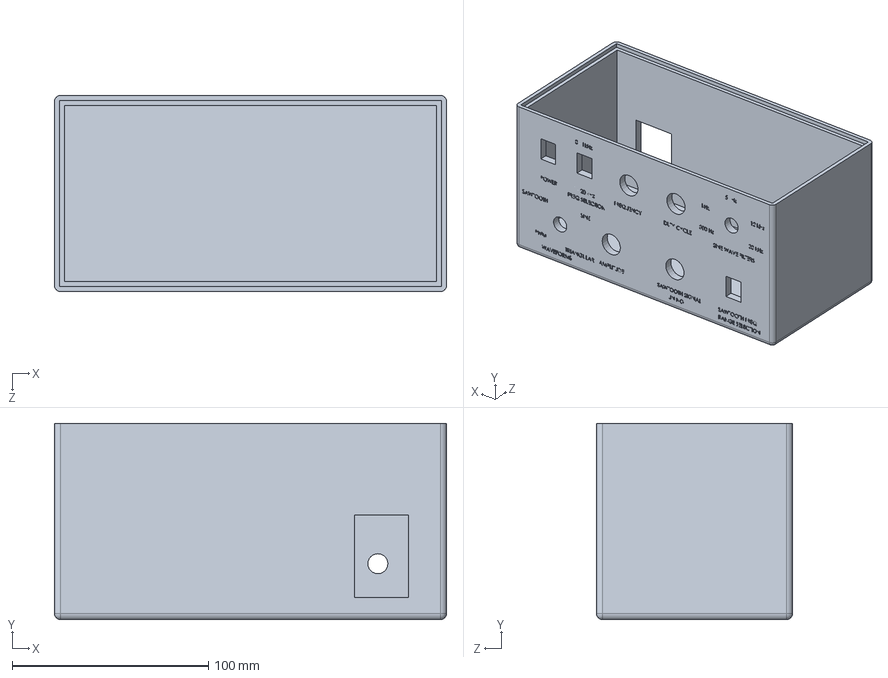
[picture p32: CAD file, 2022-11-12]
function generator enclosure/box.SLDPRT
200.0 x 100.0 x 100.0 mm

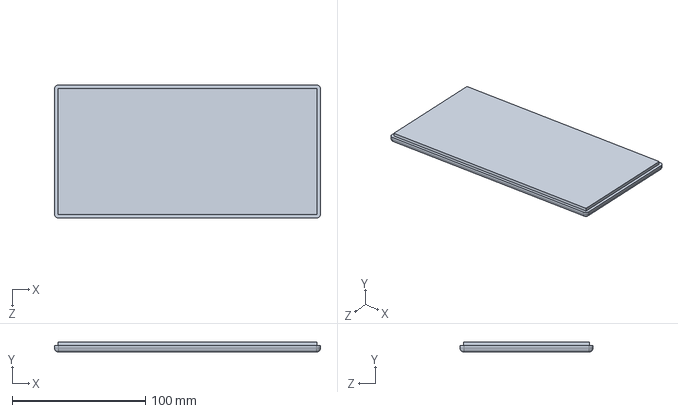
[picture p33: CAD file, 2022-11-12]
function generator enclosure/lid.SLDPRT
200.0 x 7.50 x 100.0 mm

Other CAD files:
function generator enclosure/controlknob/Perilla aire acondicionado.SLDPRT
function generator enclosure/ac/AC Input Connector and Switch.x_t
function generator enclosure/rocker switch 1.IGS
function generator enclosure/rocker switch 1.stl
